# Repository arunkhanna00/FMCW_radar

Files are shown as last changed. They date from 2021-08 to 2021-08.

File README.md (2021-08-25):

# FMCW-radar
An FMCW radar PCB. 

Inspired by [Gregory L. Charvat's Coffee Can Radar](https://ocw.mit.edu/resources/res-ll-003-build-a-small-radar-system-capable-of-sensing-range-doppler-and-synthetic-aperture-radar-imaging-january-iap-2011/)

Here is a basic idea of how the radar works:
radar_guide

The schematic and PCB are shown below:
radar_pic
schematic

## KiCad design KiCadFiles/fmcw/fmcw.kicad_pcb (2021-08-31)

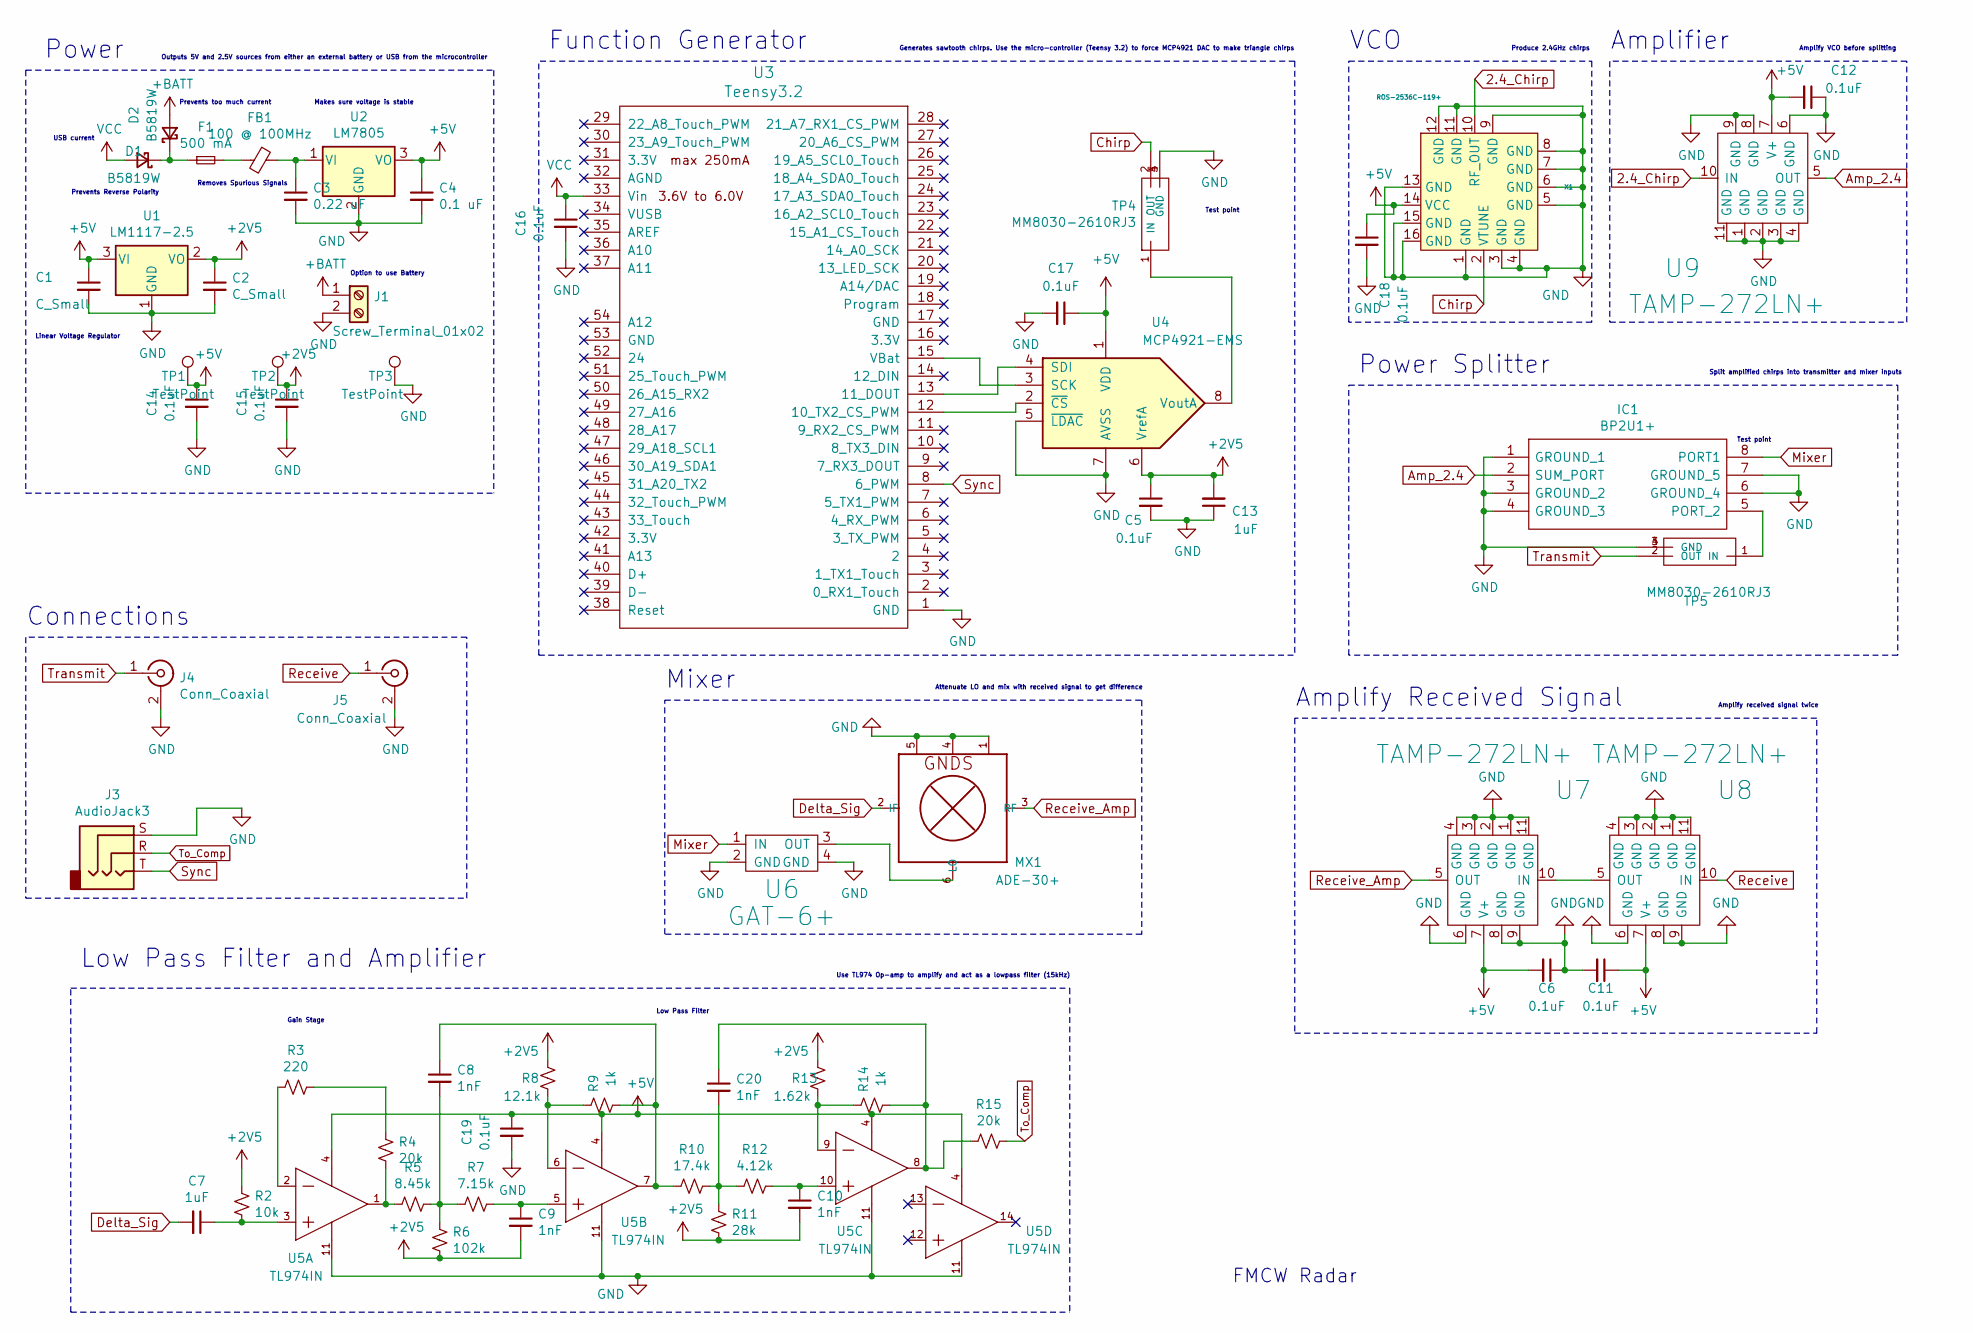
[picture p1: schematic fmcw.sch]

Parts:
C1, C2: C_Small; C_0603_1608Metric
C3: 0.22 uF; C_0603_1608Metric
C4: 0.1 uF; C_0603_1608Metric
C5, C6, C11, C12, C14, C15, C16, C17, C18, C19: 0.1uF; C_0603_1608Metric
C7, C13: 1uF; C_0603_1608Metric
C8, C9, C10, C20: 1nF; C_0603_1608Metric
D1, D2: B5819W; D_0603_1608Metric
F1: 500 mA; Fuse_1206_3216Metric
FB1: 100 @ 100MHz
IC1: BP2U1+; SOIC127P597X196-8N; Manufacturer_Part_Number BP2U1+
J1: Screw_Terminal_01x02; TerminalBlock_4Ucon_1x02_P3.50mm_Horizontal
J3: AudioJack3; Jack_3.5mm_CUI_SJ-3523-SMT_Horizontal
J4, J5: Conn_Coaxial; SMA_Amphenol_132289_EdgeMount
MX1: ADE-30+; CD636
R2: 10k; R_0603_1608Metric
R3: 220; R_0603_1608Metric
R4, R15: 20k; R_0603_1608Metric
R5: 8.45k; R_0603_1608Metric
R6: 102k; R_0603_1608Metric
R7: 7.15k; R_0603_1608Metric
R8: 12.1k; R_0603_1608Metric
R9, R14: 1k; R_0603_1608Metric
R10: 17.4k; R_0603_1608Metric
R11: 28k; R_0603_1608Metric
R12: 4.12k; R_0603_1608Metric
R13: 1.62k; R_0603_1608Metric
TP1, TP2, TP3: TestPoint; TestPoint_Pad_1.0x1.0mm
TP4, TP5: MM8030-2610RJ3; MURATA_MM8030-2610RJ3; PARTREV Nov. 1, 2018
U1: LM1117-2.5; SOT-223
U2: LM7805; SOT-223
U3: Teensy3.2; Teensy30_31_32_LC
U4: MCP4921-EMS; MCP4921-E_SN
U5: TL974IN; Texas_Instruments-TL974IN-Manufacturer_Recommended; Rating Catalog
U6: GAT-6+; GAT-3
U7, U8, U9: TAMP-272LN+
X1: ROS-2536C-119+; ROS­2536C­119

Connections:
2.4_Chirp: U9.10 (IN), X1.10 (RF_OUT)
+2V5: C2.1, C5.1, C9.2, C10.2, C13.2, C15.1, R2.1, R6.2, R8.1, R11.2, R13.1, TP2.1, U1.2 (VO), U1.4, U4.6 (VrefA)
+5V: C1.1, C4.1, C6.2, C11.1, C12.2, C14.1, C17.1, C18.1, C19.1, TP1.1, U1.3 (VI), U2.3 (VO), U2.4, U4.1 (VDD), U5.4 (VCC+), U7.7 (V+), U8.7 (V+), U9.7 (V+), X1.14 (VCC)
+BATT: D2.2 (A), J1.1
Amp_2.4: IC1.2 (SUM_PORT), U9.5 (OUT)
Chirp: TP4.2 (OUT), X1.2 (VTUNE)
Delta_Sig: C7.2, MX1.2 (IF)
GND: C1.2, C2.2, C3.2, C4.2, C5.2, C6.1, C11.2, C12.1, C13.1, C14.2, C15.2, C16.2, C17.2, C18.2, C19.2, IC1.1 (GROUND_1), IC1.3 (GROUND_2), IC1.4 (GROUND_3), IC1.6 (GROUND_4), IC1.7 (GROUND_5), J1.2, J3.S, J4.2 (Ext), J5.2 (Ext), MX1.1, MX1.4, MX1.5, TP3.1, TP4.3 (GND), TP4.4 (GND), TP5.3 (GND), TP5.4 (GND), U1.1 (GND), U2.2 (GND), U3.1 (GND), U4.5 (~LDAC~), U4.7 (AVSS), U5.11 (VCC-), U6.2 (GND), U6.4 (GND), U7.1 (GND), U7.2 (GND), U7.3 (GND), U7.4 (GND), U7.6 (GND), U7.8 (GND), U7.9 (GND), U7.11 (GND), U8.1 (GND), U8.2 (GND), U8.3 (GND), U8.4 (GND), U8.6 (GND), U8.8 (GND), U8.9 (GND), U8.11 (GND), U9.1 (GND), U9.2 (GND), U9.3 (GND), U9.4 (GND), U9.6 (GND), U9.8 (GND), U9.9 (GND), U9.11 (GND), X1.1 (GND), X1.3 (GND), X1.4 (GND), X1.5 (GND), X1.6 (GND), X1.7 (GND), X1.8 (GND), X1.9 (GND), X1.11 (GND), X1.12 (GND), X1.13 (GND), X1.15 (GND), X1.16 (GND)
Mixer: IC1.8 (PORT1), U6.1 (IN)
unnamed: C3.1, FB1.1, U2.1 (VI)
unnamed: C7.1, R2.2, U5.3 (IN1+)
unnamed: C8.1, R9.2, R10.2, U5.7 (OUT2)
unnamed: C8.2, R5.1, R6.1, R7.2
unnamed: C9.1, R7.1, U5.5 (IN2+)
unnamed: C10.1, R12.1, U5.10 (IN3+)
unnamed: C20.1, R14.2, R15.1, U5.8 (OUT3)
unnamed: C20.2, R10.1, R11.1, R12.2
unnamed: D1.1 (K), D2.1 (K), F1.1
unnamed: F1.2, FB1.2
unnamed: IC1.5 (PORT_2), TP5.1 (IN)
unnamed: MX1.6 (LO), U6.3 (OUT)
unnamed: R3.1, U5.2 (IN1-)
unnamed: R3.2, R4.1
unnamed: R4.2, R5.2, U5.1 (OUT1)
unnamed: R8.2, R9.1, U5.6 (IN2-)
unnamed: R13.2, R14.1, U5.9 (IN3-)
unnamed: TP4.1 (IN), U4.8 (VoutA)
unnamed: U3.12 (10_TX2_CS_PWM), U4.2 (~CS~)
unnamed: U3.13 (11_DOUT), U4.4 (SDI)
unnamed: U3.15 (VBat), U4.3 (SCK)
unnamed: U7.10 (IN), U8.5 (OUT)
Receive: J5.1 (In), U8.10 (IN)
Receive_Amp: MX1.3 (RF), U7.5 (OUT)
Sync: J3.T, U3.8 (6_PWM)
To_Comp: J3.R, R15.2
Transmit: J4.1 (In), TP5.2 (OUT)
VCC: C16.1, D1.2 (A), U3.33 (Vin)

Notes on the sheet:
Prevents Reverse Polarity
Prevents too much current
Makes sure voltage is stable
USB current
Linear Voltage Regulator
Power
Function Generator
Outputs 5V and 2.5V sources from either an external battery or USB from the microcontroller
Generates sawtooth chirps. Use the micro-controller (Teensy 3.2) to force MCP4921 DAC to make triangle chirps
Test point
Low Pass Filter and Amplifier
Gain Stage
Low Pass Filter
VCO
Produce 2.4GHz chirps
Amplifier
Power Splitter
Split amplified chirps into transmitter and mixer inputs
Amplify VCO before splitting
Use TL974 Op-amp to amplify and act as a lowpass filter (15kHz)
Connections
Mixer
Attenuate LO and mix with received signal to get difference
Amplify Received Signal
Amplify received signal twice
FMCW Radar
Option to use Battery
Removes Spurious Signals

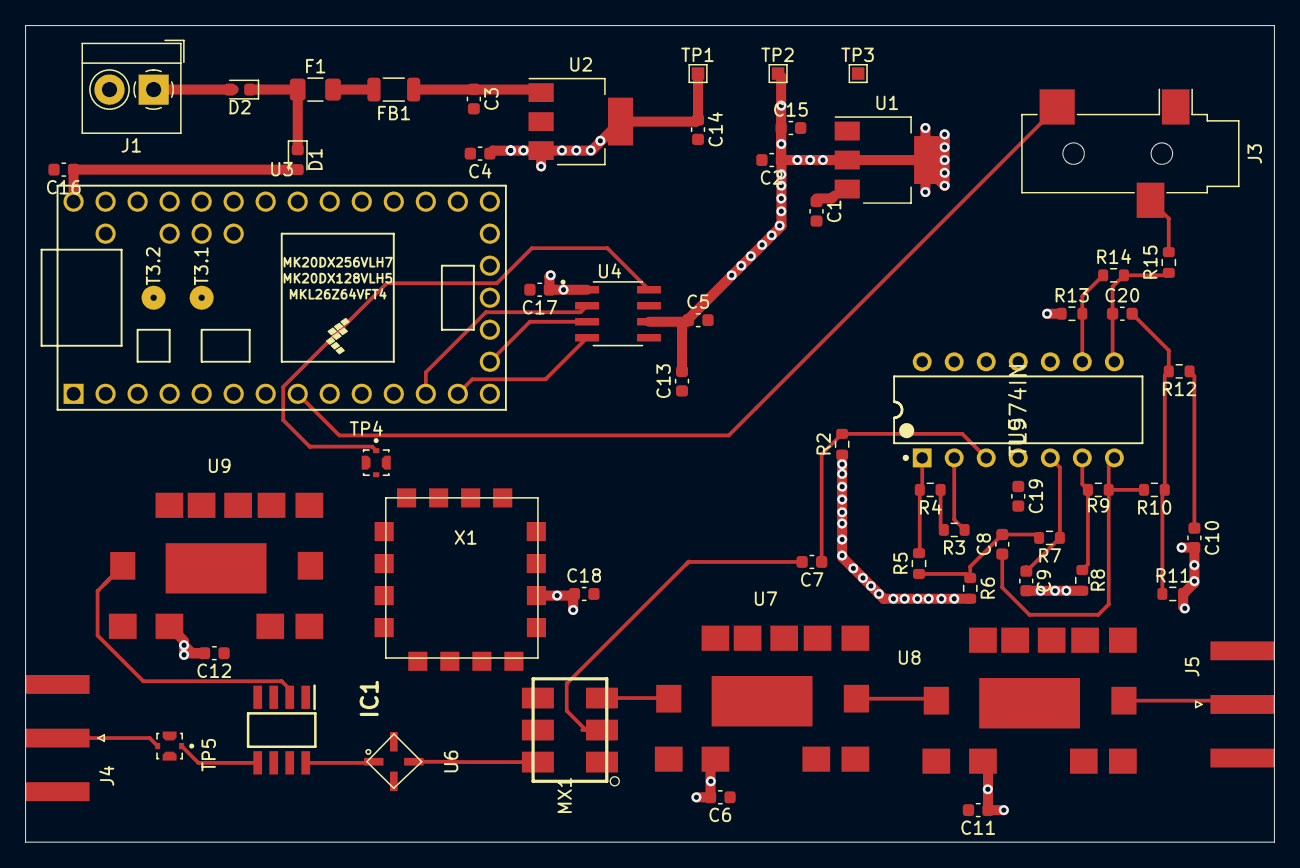
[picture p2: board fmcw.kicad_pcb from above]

Board: 4 copper layers, 99.1 x 64.8 mm, 59 parts (0 on the bottom side), 37 nets.

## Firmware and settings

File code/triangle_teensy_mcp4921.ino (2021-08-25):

/*
Triangle wave and sync pulse generator to control a (0-5V input range) VCO for FMCW radar.
The MPC4921 DAC is used to generate a triangle wave with a period of 40ms.
PWM of the Arduino UNO is use to simultaneously generate the sync pulse,
used for signal processing.


*/

#include <SPI.h> // Include the SPI library 

word outputValue = 4;// A word is a 16-bit number
int incr = 4;

const int slaveSelectPin = 10; //set the slave select (chip select) pin number
const int SYNC = 8;  //set the SYNC output pin number
 
void setup()
{
    // Set pins for output
    pinMode(SYNC, OUTPUT);                     // SYNC pin
    digitalWrite(SYNC, LOW);               // Sync pulse low
    pinMode(slaveSelectPin, OUTPUT);                    // Slave-select (SS) pin
    SPI.begin();                            // Activate the SPI bus
    SPI.beginTransaction(SPISettings(16000000, MSBFIRST, SPI_MODE0));  // Set up the SPI transaction; this is not very elegant as there is never a close transaction action.
}

void loop()
{


    if (outputValue == 4092 || outputValue == 0){
      incr = -incr;
      digitalWrite(SYNC, !digitalRead(SYNC));
    }
    
    outputValue = outputValue + incr;

    byte HighByte =highByte(outputValue);    // Take the upper byte
    HighByte = 0b00001111 & HighByte;       // Shift in the four upper bits (12 bit total)
    HighByte = 0b00110000 | HighByte;       // Keep the Gain at 1 and the Shutdown(active low) pin off
    byte LowByte = lowByte(outputValue);     // Shift in the 8 lower bits
    
    digitalWrite(slaveSelectPin, LOW);          
    SPI.transfer(HighByte);            // Send the upper byte
    SPI.transfer(LowByte);             // Send the lower byte
    digitalWrite(slaveSelectPin, HIGH);         // Turn off the SPI transmission
}
